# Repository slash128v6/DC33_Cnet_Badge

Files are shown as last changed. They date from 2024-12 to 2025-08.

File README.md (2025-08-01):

# DC33 CompuNet Badge - The Meshtastic Express

Introducing **The Meshtastic Express** — the open-source, networkless pager built for hackers, tinkerers, and technophiles. Powered by the Meshtastic protocol and fully customizable from the firmware up, this device lets you send messages over a decentralized mesh network — no cell towers, no Wi-Fi, no problem. Flash your own firmware, tweak the hardware with this highly customizable device and relive the 1990’s glory of belt-clip attached electronics.

Meshtastic devices use **LoRa (Long Range)** radio technology to send small data packets over several kilometers. Each device acts as a node in the mesh, forwarding messages to others until they reach their destination. Learn more at: 

[https://github.com/slash128v6/DC33_Cnet_Badge](https://github.com/slash128v6/DC33_Cnet_Badge)

[https://meshtastic.org](https://github.com/slash128v6/DC33_Cnet_Badge)

> [!TIP]
> **WARNING – DO NOT POWER THE HELTEC V3 LoRa UNIT WITHOUT THE ANTENNA ATTACHED! DAMAGE MAY RESULT**

# Section 1: Hardware Assembly

1.	Verify inventory:

| Qty	| Description |
|---|---|
|1	|PCB |
|1	|Heltec V3 LoRa Module Kit (includes antenna and 2x 18 pin headers)|
|1	|LiPo Battery|
|1	|GPS Module|
|1	|GPS Antenna|
|1	|Piezo Buzzer|
|1	|Vibration Motor|
|1	|6 Pin SAO Header|
|1	|12 Pin Header|
|2	|VHB Pads|
|1	|Case Bottom|
|1	|Case Top|
|1	|Case Clip|

2.	Solder the vibration motor. You can trim the wires but be very careful when stripping the ends, as the wire is very small gauge and easy to cut when stripping. Peel off the white tab and stick to the PCB. 

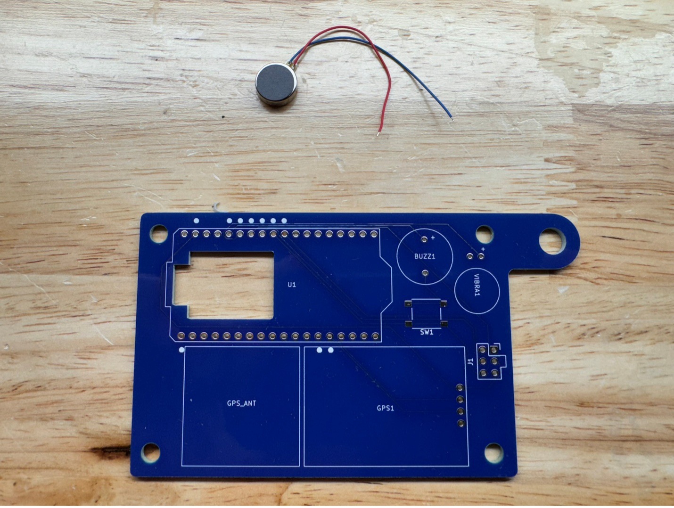
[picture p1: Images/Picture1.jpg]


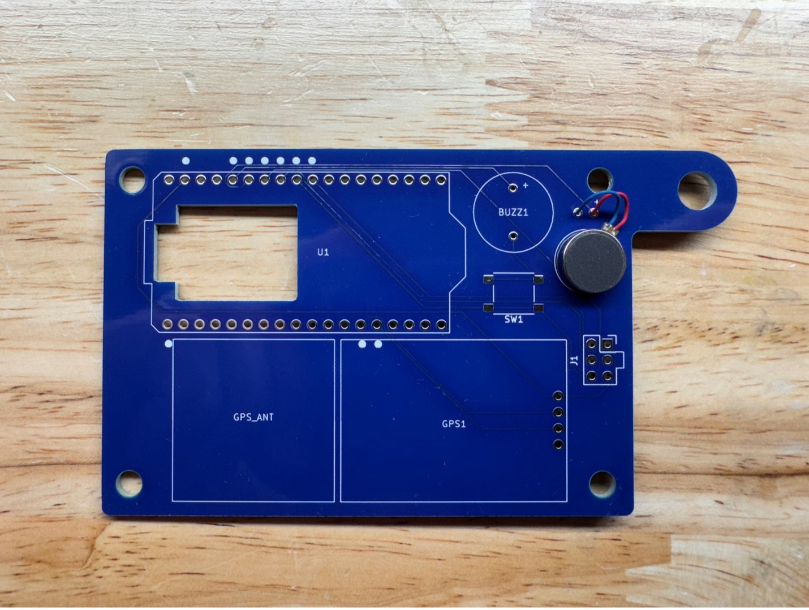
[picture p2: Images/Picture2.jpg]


3.	Solder the 6 pin SAO header with the tab aligned with the white silkscreen outline. Try to keep it as square as possible so SAOs are not crooked when installed. 

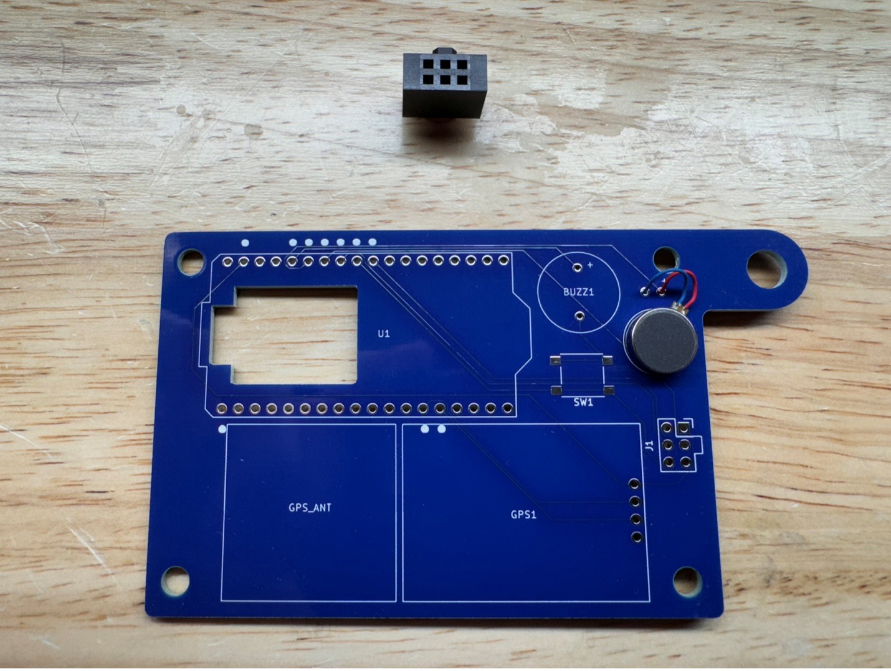
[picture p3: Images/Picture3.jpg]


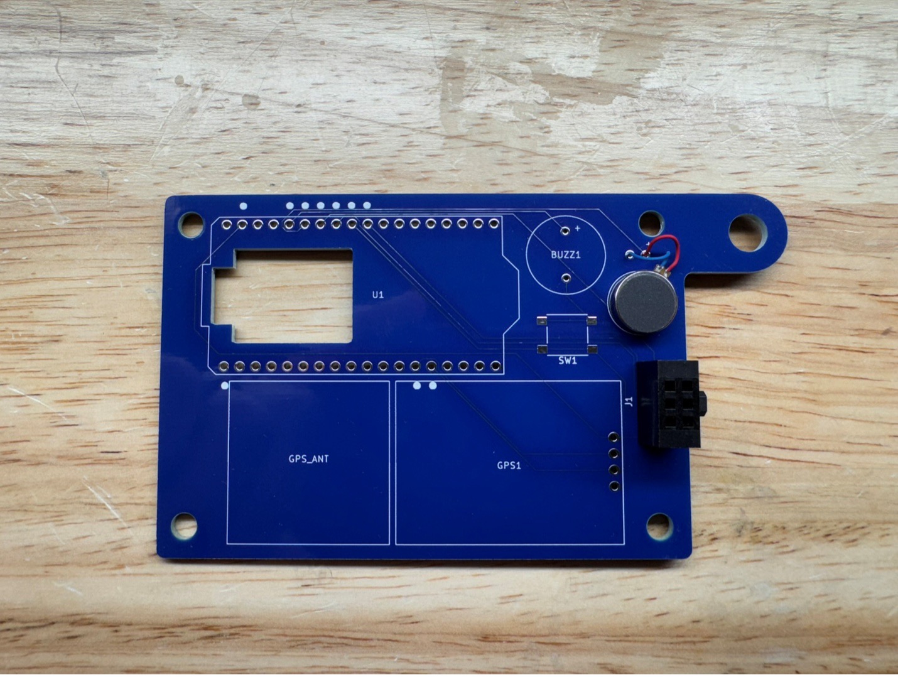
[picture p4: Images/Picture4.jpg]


4.	Solder the piezo buzzer noting the polarity. Remove the protective white sticker.

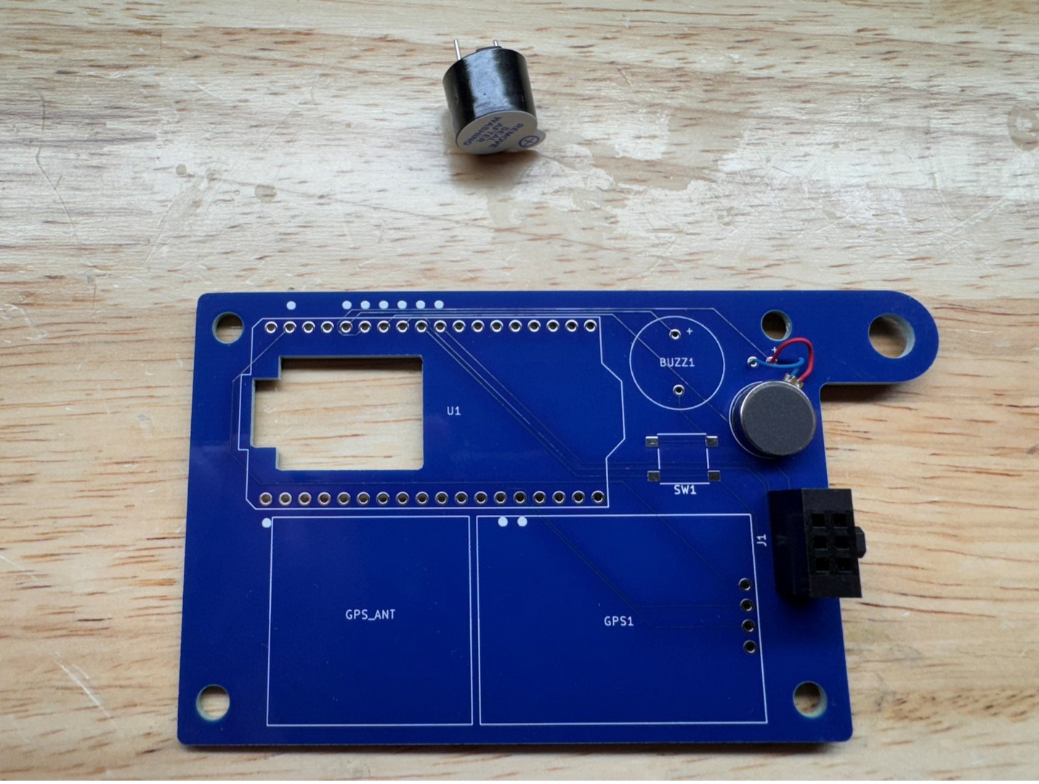
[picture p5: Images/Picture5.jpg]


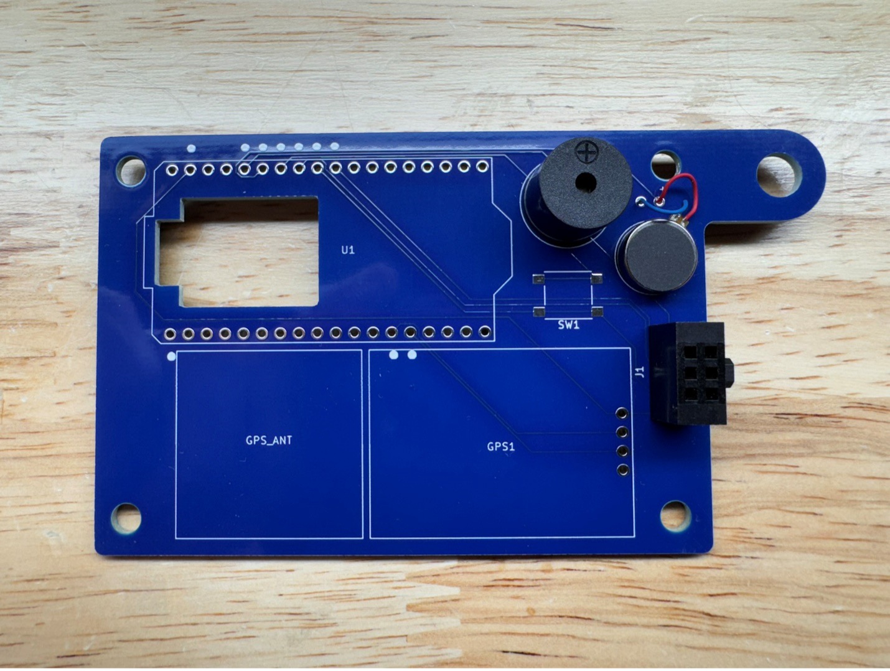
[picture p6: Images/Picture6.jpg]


5.	Solder the Heltec V3 LoRo module to the PCB using the 2x 18 pin headers included in the kit. The short side of the pins should face up through the module and the long side should face down through the PCB. To save time soldering, only the pins marked with white dots need to be soldered. Be careful soldering the 2 pins under the display ribbon cable. The cable is heat resistant, but can melt with too much heat.

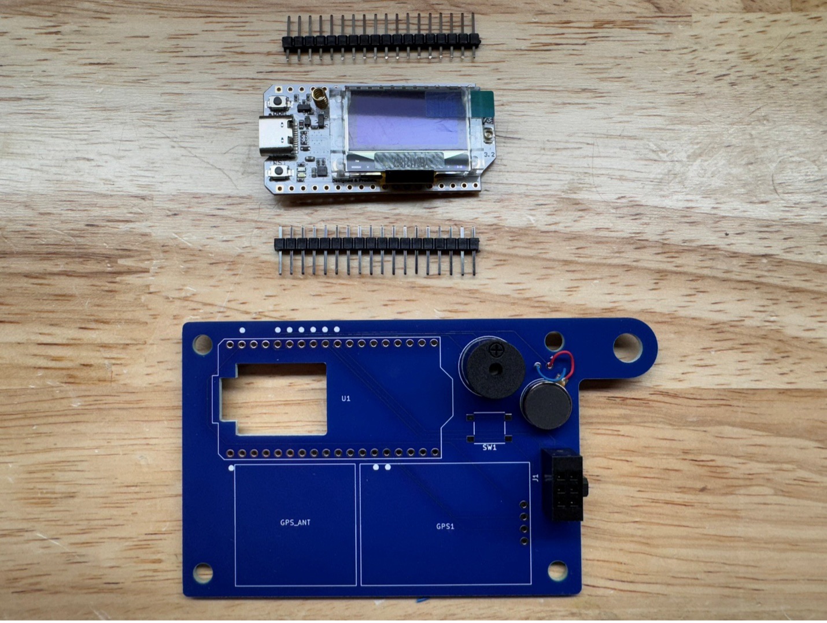
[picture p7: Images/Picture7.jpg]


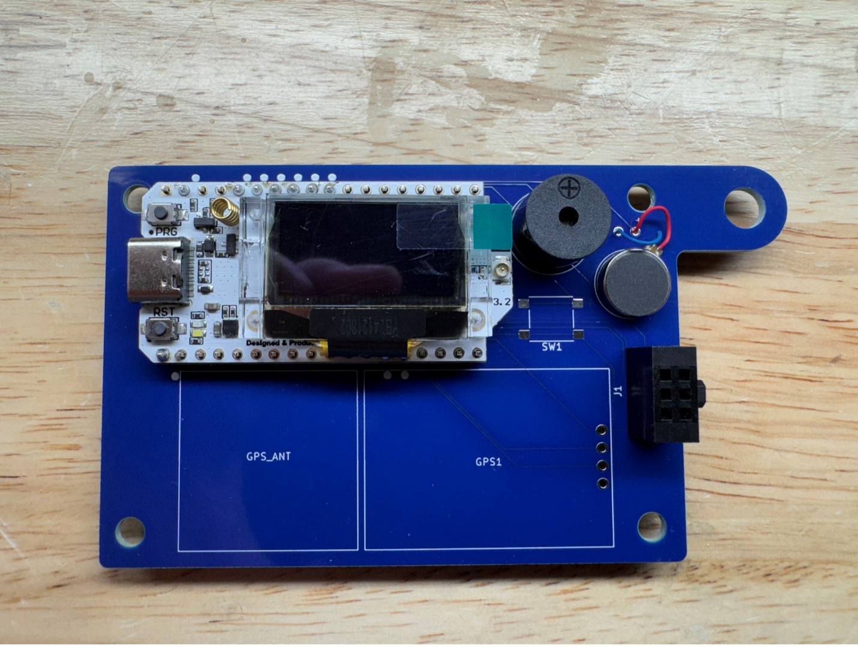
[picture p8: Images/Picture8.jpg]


6.	Cut off 4 pins from the 12 pin header and solder the GPS module to the PCB. The short side of the pins should face up through the module and the long side should face down through the PCB.

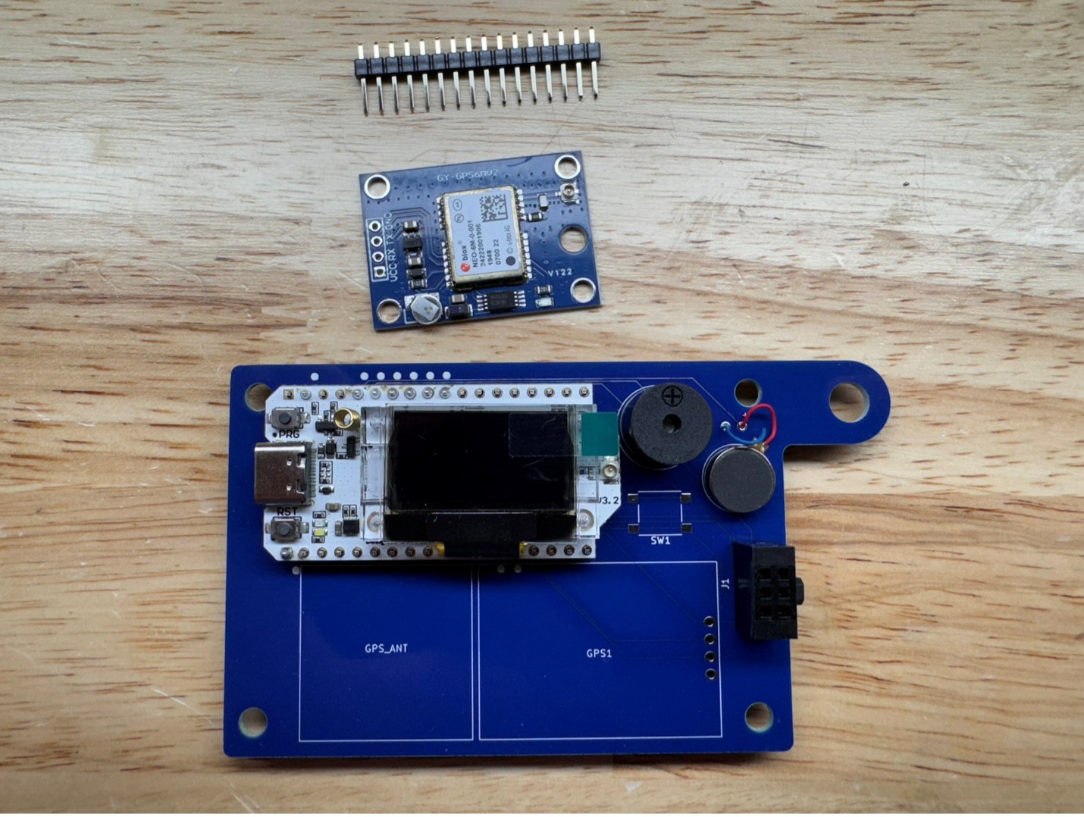
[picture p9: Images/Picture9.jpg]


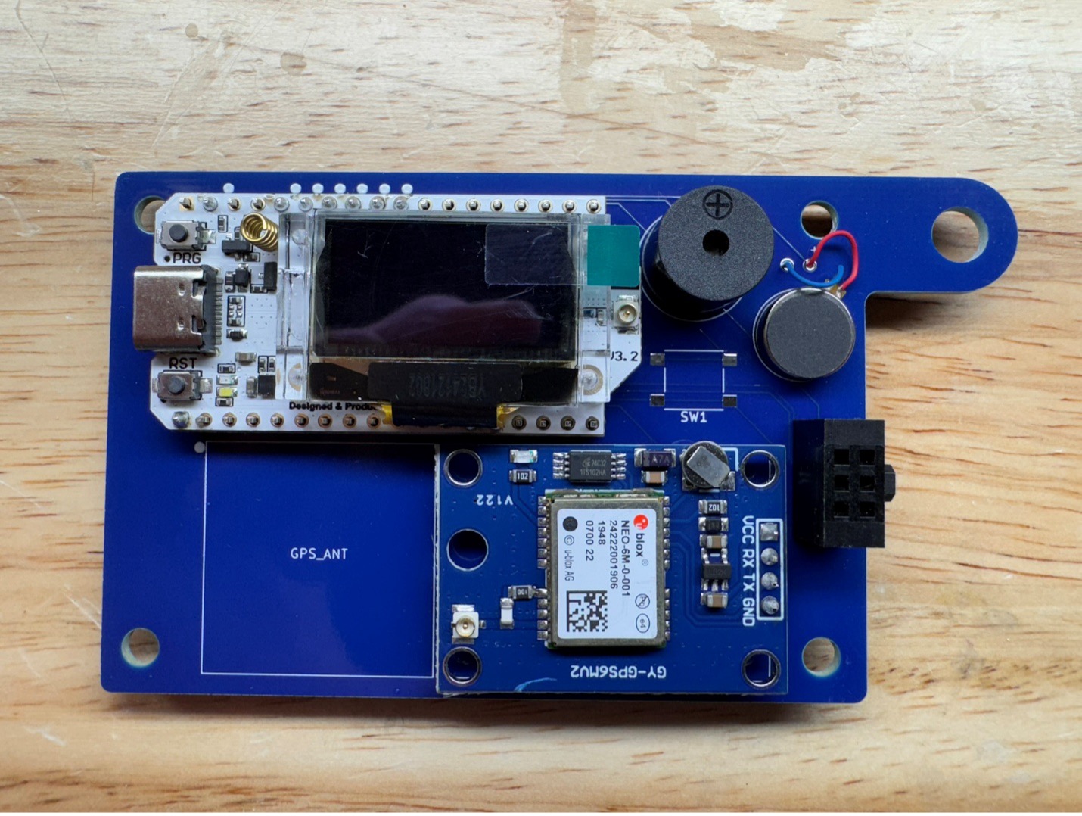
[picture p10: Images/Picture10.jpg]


7.	Attach the GPS antenna to the GPS module, pressing the connectors together until there is a slight click and they are parallel when viewed from the side. A fingernail or small flat bladed tool is helpful. Using one of the VHB pads affix the GPS antenna to the PCB, routing the wire underneath the lip. Make sure the GPS antenna is within the white square outline so the case will fit on later.

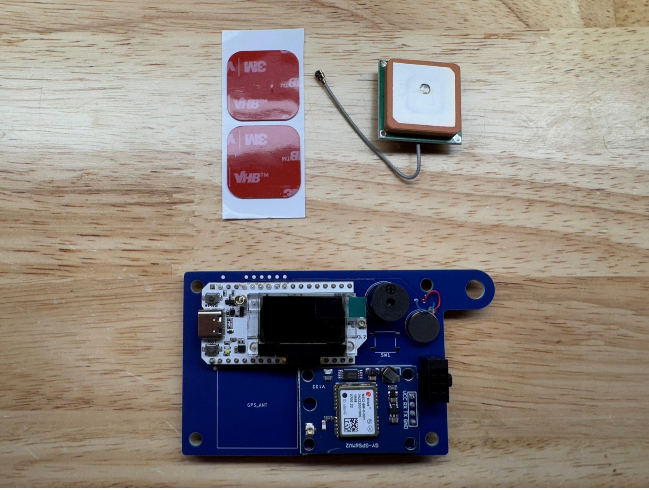
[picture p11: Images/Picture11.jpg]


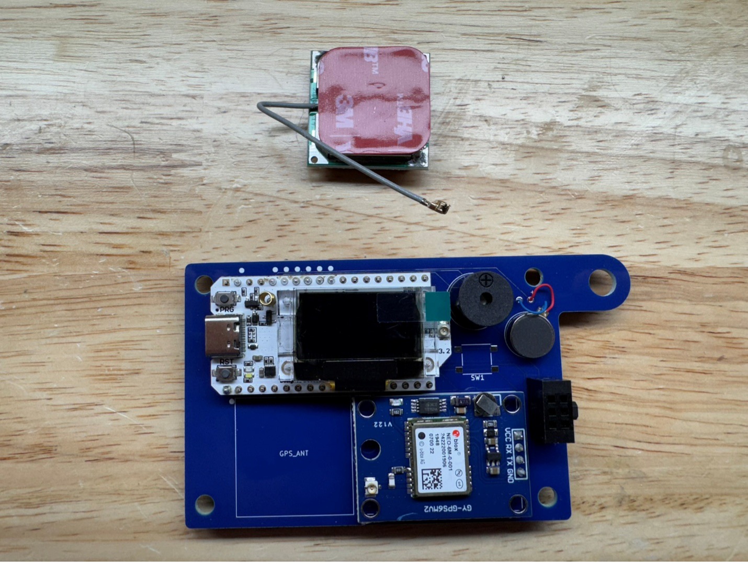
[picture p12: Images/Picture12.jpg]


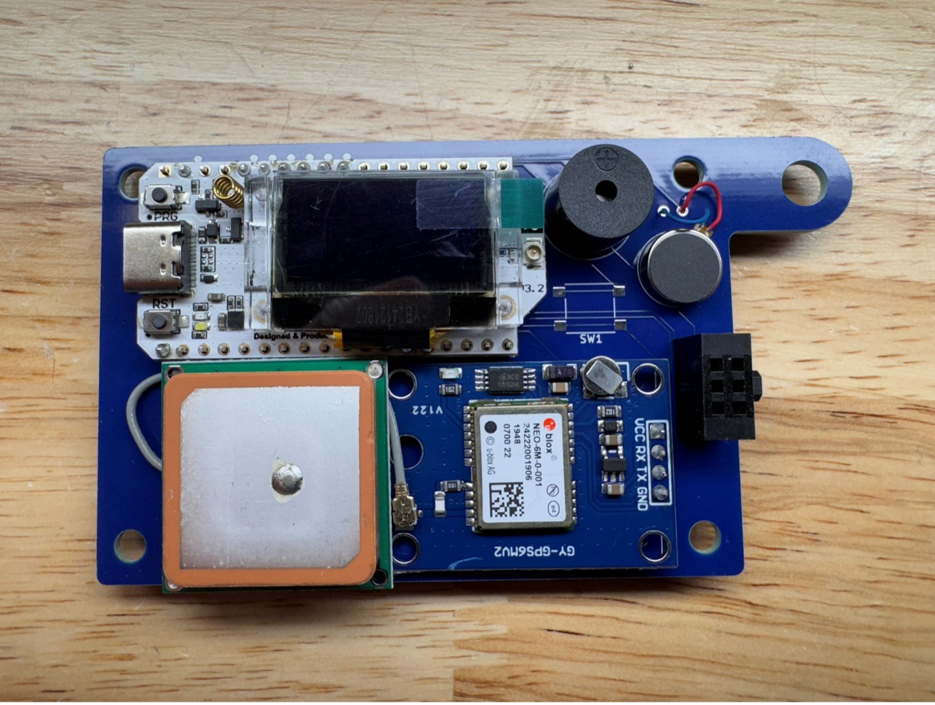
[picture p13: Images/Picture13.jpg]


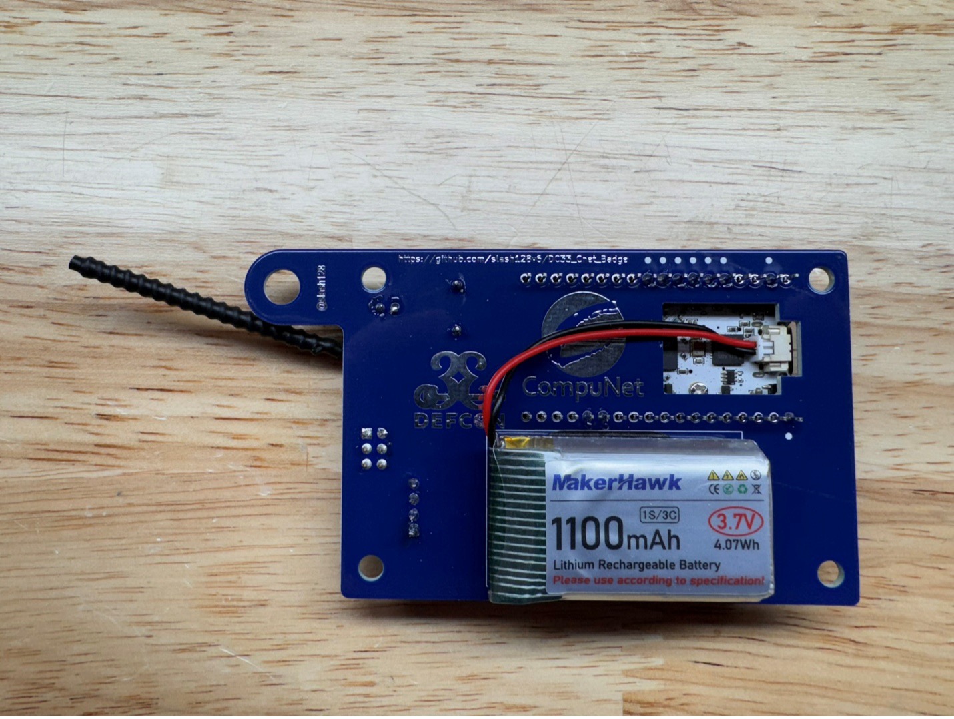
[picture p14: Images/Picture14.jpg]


8.	Mount the PCB in the lower case. Route the LoRa antenna horizontally along the top edge of the PCB as shown. A piece of tape helps. Align the top half of the case onto the lower half posts and press together until the gap between the two halves is gone. 

Slide the clip into the opening on the back until it clicks into place. 

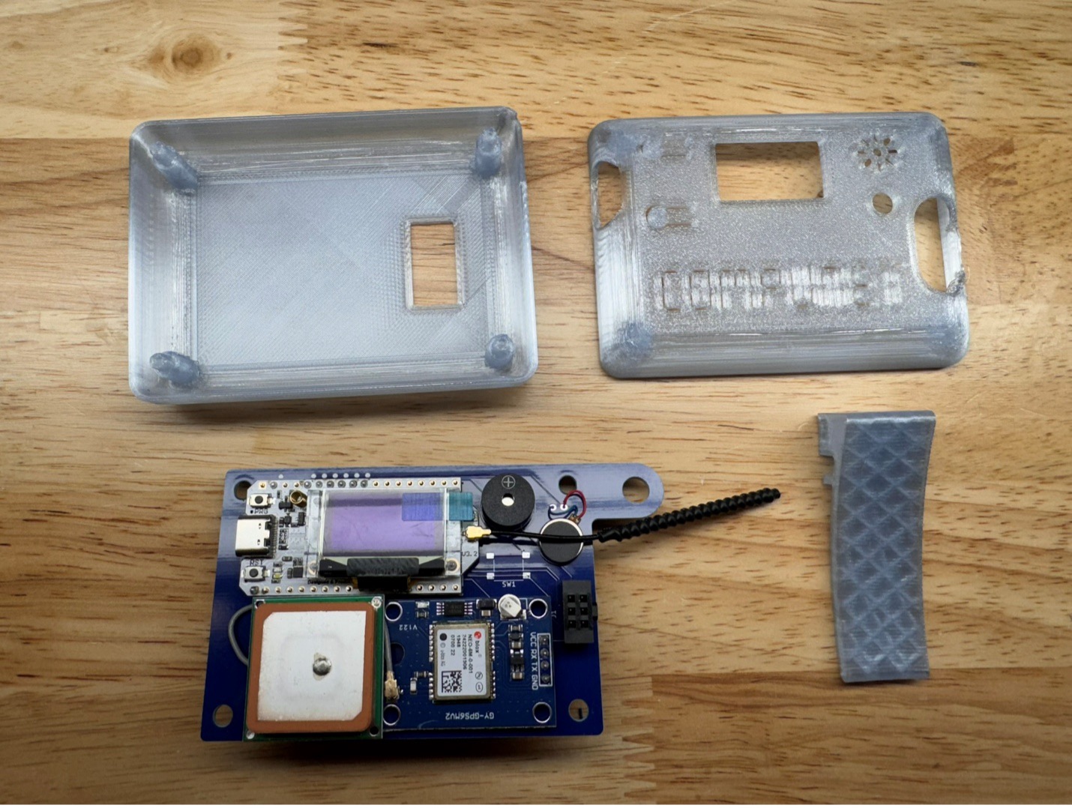
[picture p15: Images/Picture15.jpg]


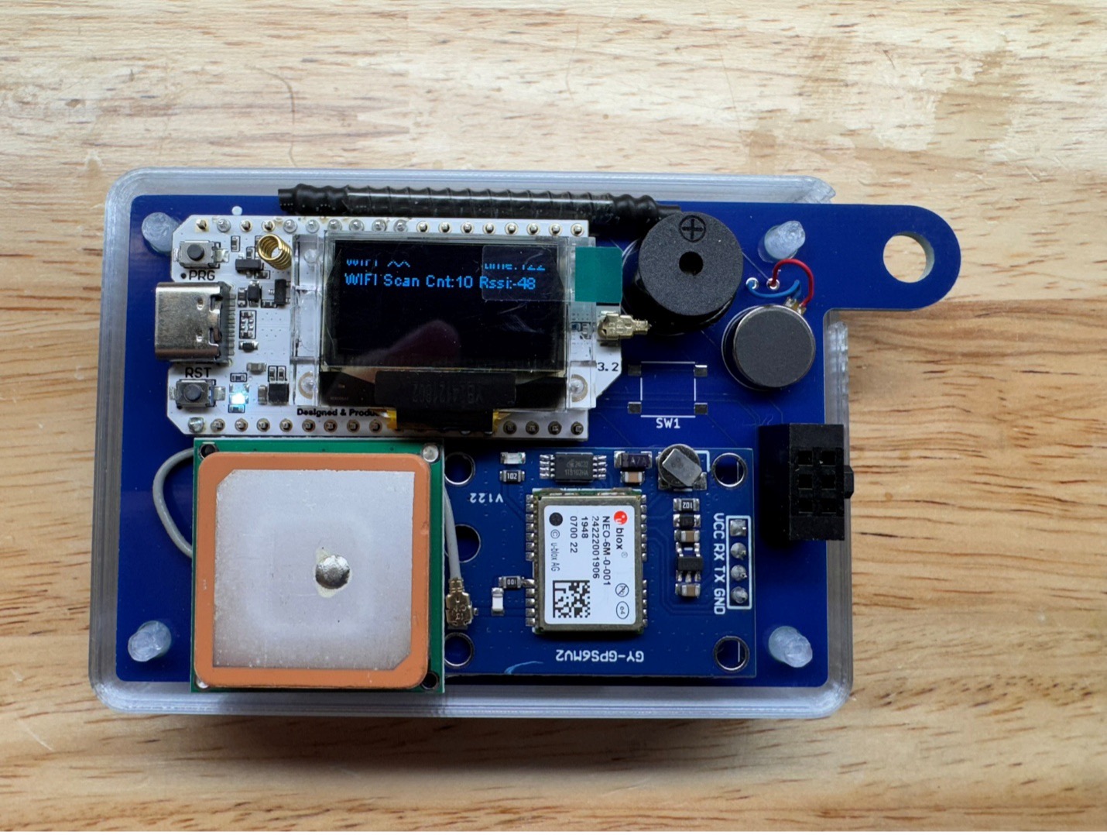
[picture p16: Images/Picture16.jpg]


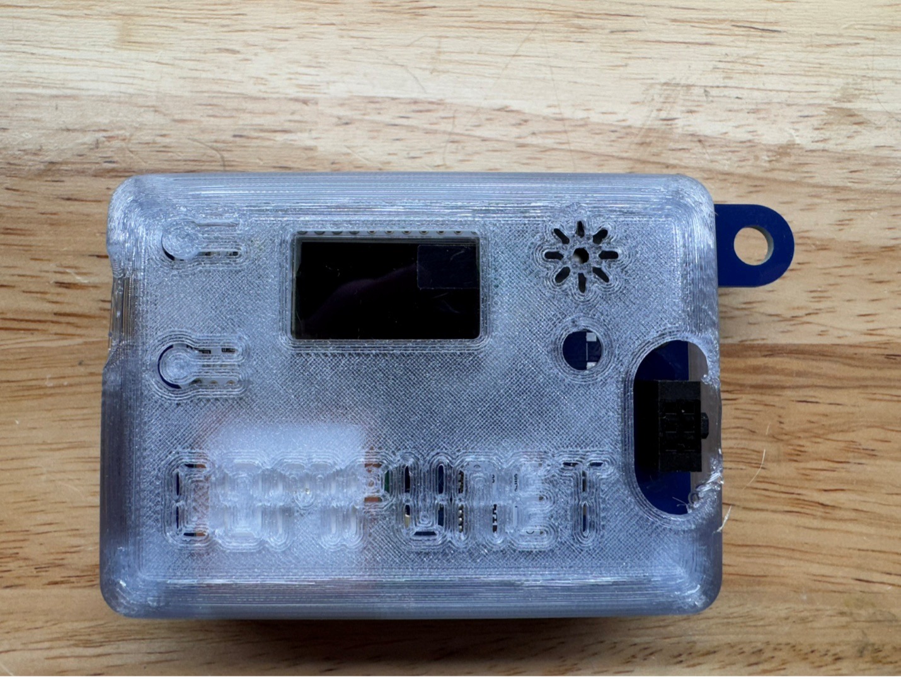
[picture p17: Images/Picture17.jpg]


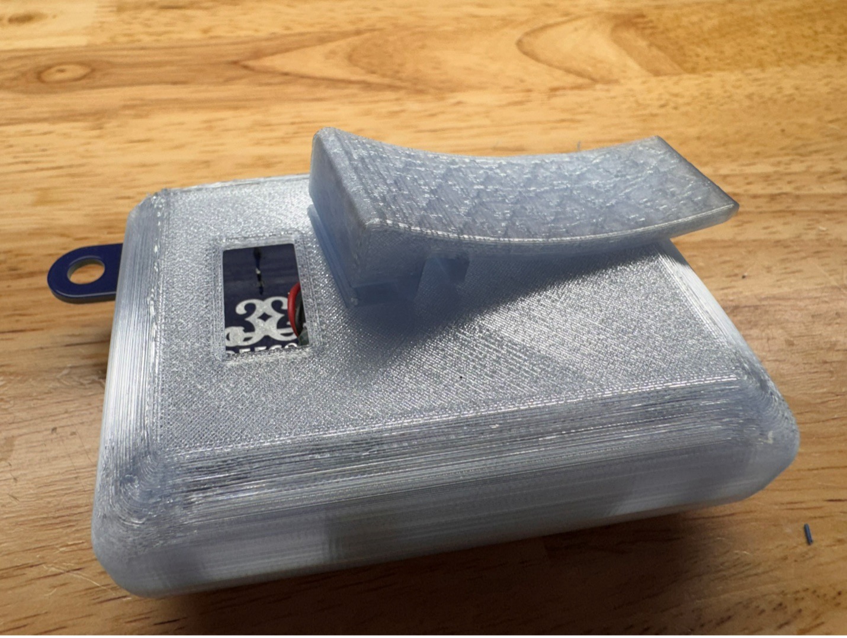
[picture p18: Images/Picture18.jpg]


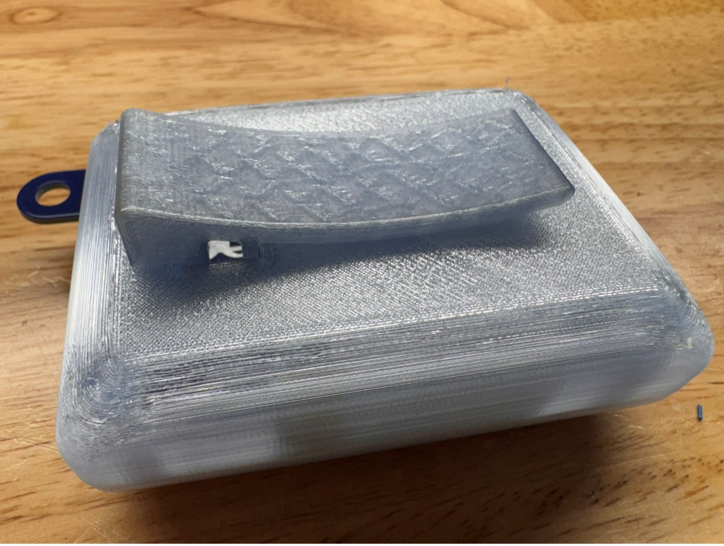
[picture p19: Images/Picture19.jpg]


# Section 2: Flashing & Configuration

1.	Install the CP210x Universal Windows Driver from https://www.silabs.com/developer-tools/usb-to-uart-bridge-vcp-drivers?tab=downloads. 

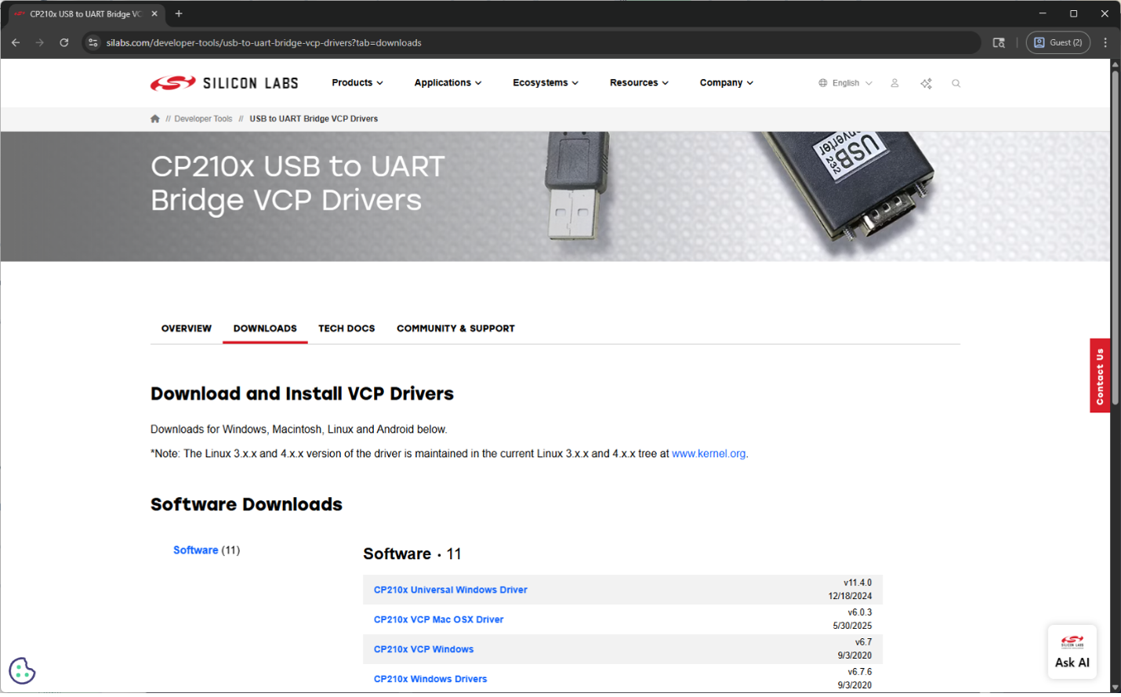
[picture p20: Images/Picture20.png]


2.	Connect the Heltec Lora V3 module to your PC with a USB-C cable. Open a browser to flasher.meshtastic.org. 

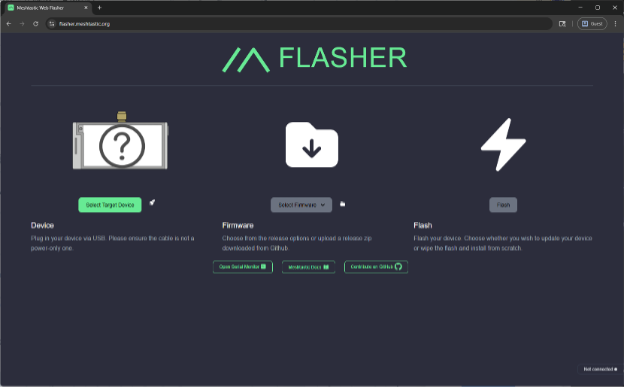
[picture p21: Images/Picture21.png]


3.	Click “Select Target Device” and select the “Heltec V3” device. 

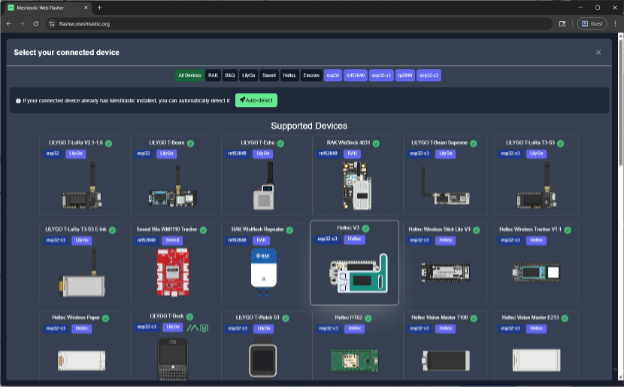
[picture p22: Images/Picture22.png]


4.	Select the latest stable firmware from the dropdown menu. 

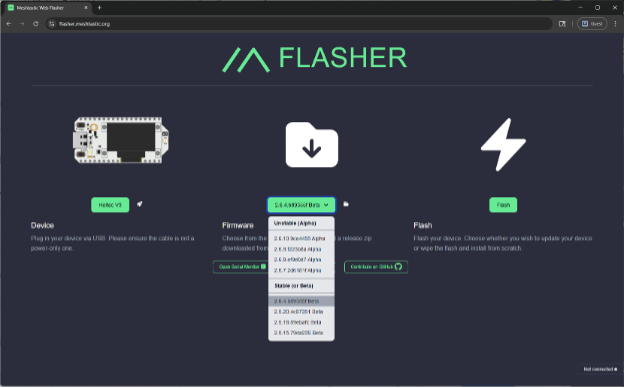
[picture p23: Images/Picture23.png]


5.	Click “Flash”. 

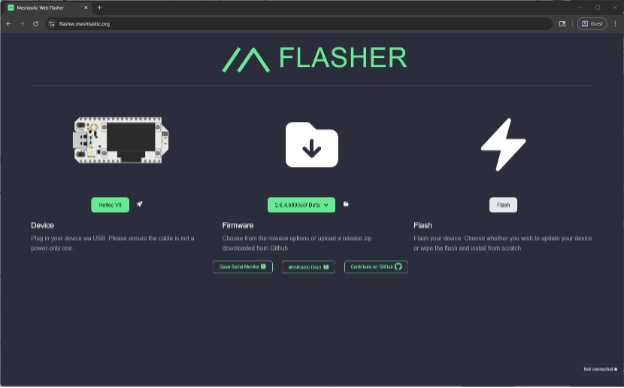
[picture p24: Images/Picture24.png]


6.	Click “Continue”.

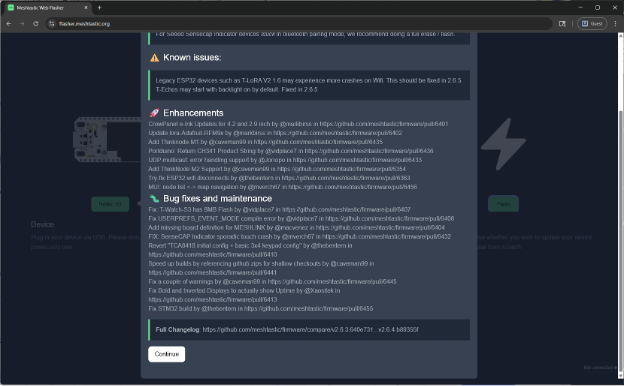
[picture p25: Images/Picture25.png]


7.	Toggle on the options “Full Erase and Install” and “Bundle Web UI” and click “Erase Flash and Install”. 

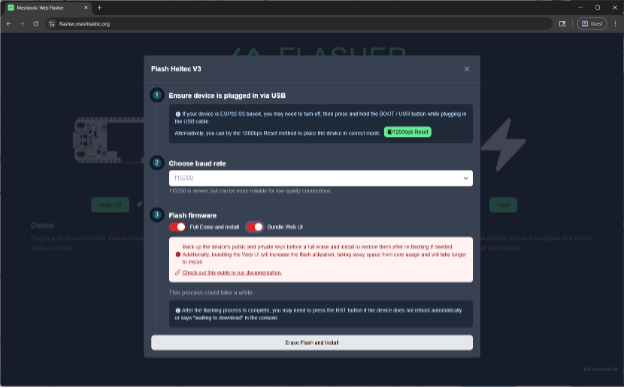
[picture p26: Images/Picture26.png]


8.	A selection dialog will appear. Select the CP2102 device and click “Connect”. 

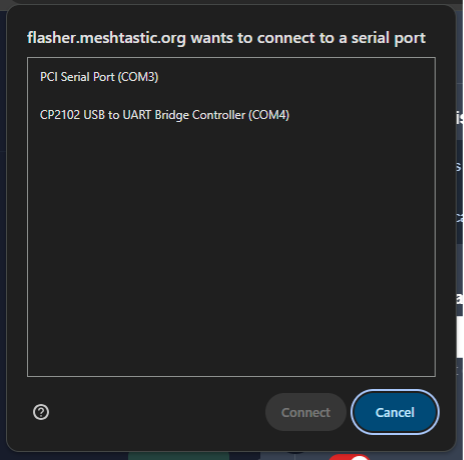
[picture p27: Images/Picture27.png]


9.	Flashing will begin. Wait for it to complete. 

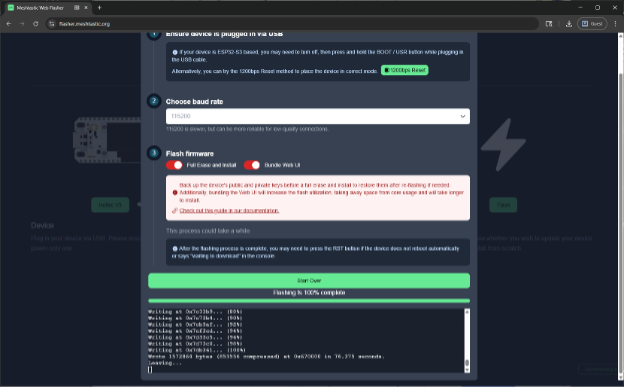
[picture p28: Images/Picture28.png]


10. Go to client.meshtastic.org and click “New Connection”. Don’t leave the flasher page open in another tab as it can interfere with the client connection. 

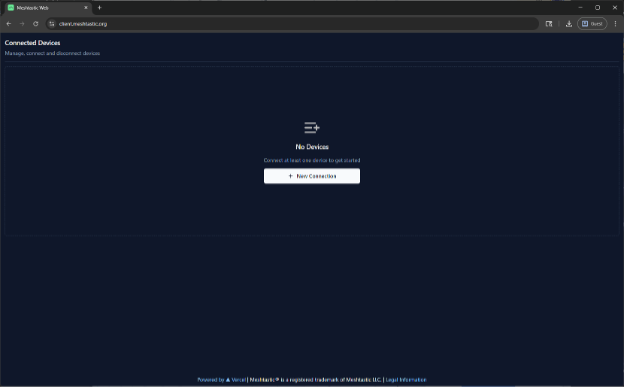
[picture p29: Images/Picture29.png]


11. Click on the “Serial” tab, then “New Device”. 

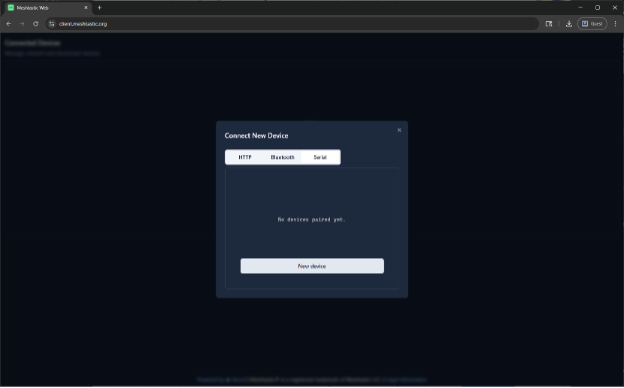
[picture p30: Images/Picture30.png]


12. A selection dialog will appear. Select the CP2102 device and click “Connect”. 

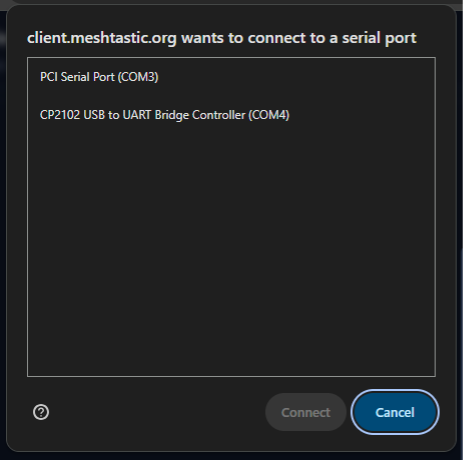
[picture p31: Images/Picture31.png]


13. Click the new device that appears. 

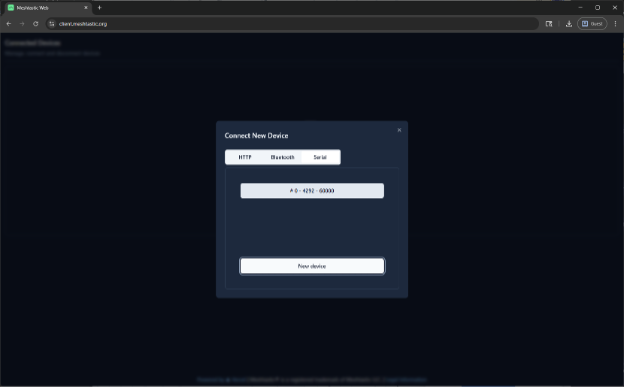
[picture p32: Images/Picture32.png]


14. Click on Config in the left menu, then the LoRa tab, set the location to “US”, then click the save floppy icon in the upper right corner. After the setting is saved the Heltec module will reboot. If it does not then try refreshing the page and try again.

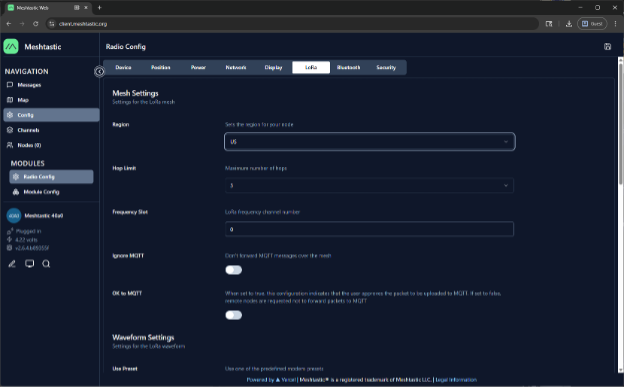
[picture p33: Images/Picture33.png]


15. Reconnect and click on the Display tab, set the Carousel Display to “15”, then click the save floppy icon in the upper right corner. After the setting is saved the Heltec module will reboot. If it does not then try refreshing the page and try again.

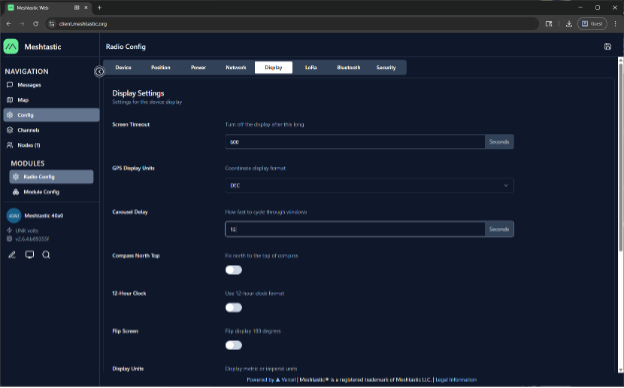
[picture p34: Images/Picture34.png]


16. Reconnect and click on the Position tab, set GPS Mode to Enables, the Receive Pin to “48” and the Transmit Pin to “47” then click the save floppy icon in the upper right corner. After the setting is saved the Heltec module will reboot. If it does not then try refreshing the page and try again.

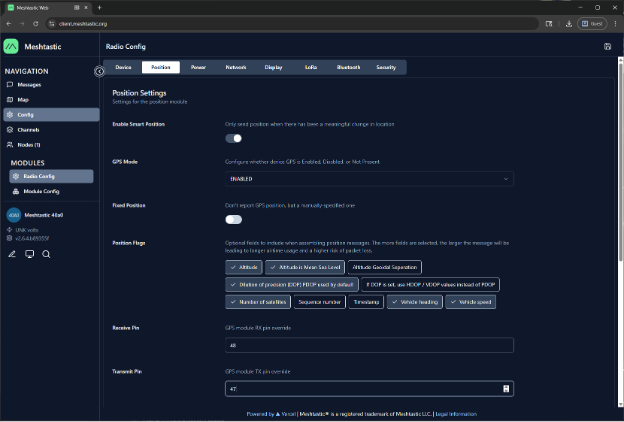
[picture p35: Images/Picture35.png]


17. Reconnect and click on Config and Module Config in the left menu, then the Ext Notif tab. Toggle on Enable External Notification then set Output Vibrate to “45” and Output Buzzer to “46” and enable all the toggle items EXCEPT “Use I2S Pin as Buzzer”, then click the save floppy icon in the upper right corner. After the setting is saved the Heltec module will reboot. If it does not then try refreshing the page and try again.

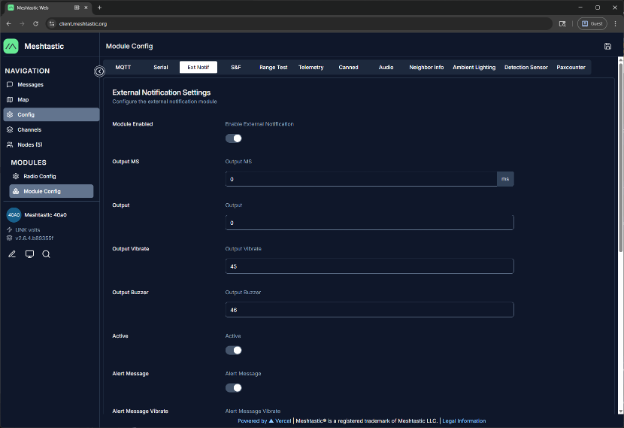
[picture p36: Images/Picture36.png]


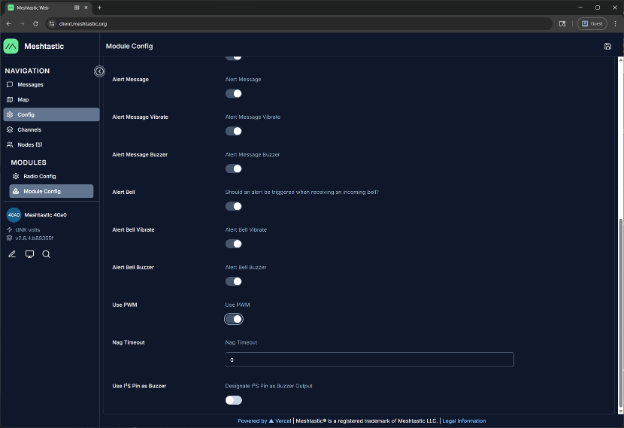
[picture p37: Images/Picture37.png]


# Section 3: Operation

1.	There are 2 buttons on the left side of the display. Some common button commands:

	*	Brief single presses of the top button will cycle through the screens on the display. By default the screen will turn off after 15 seconds. You can use the top button to wake the display. You can also set a longer screen timeout in settings.
	
	*	A long press of the top button will put the device in shutdown mode.

	*	A triple short press of the top button will disable GPS. Repeat to re-enable GPS.

	*	A single press of the top button will wake it back up. A single press of the bottom button will reboot the device. 

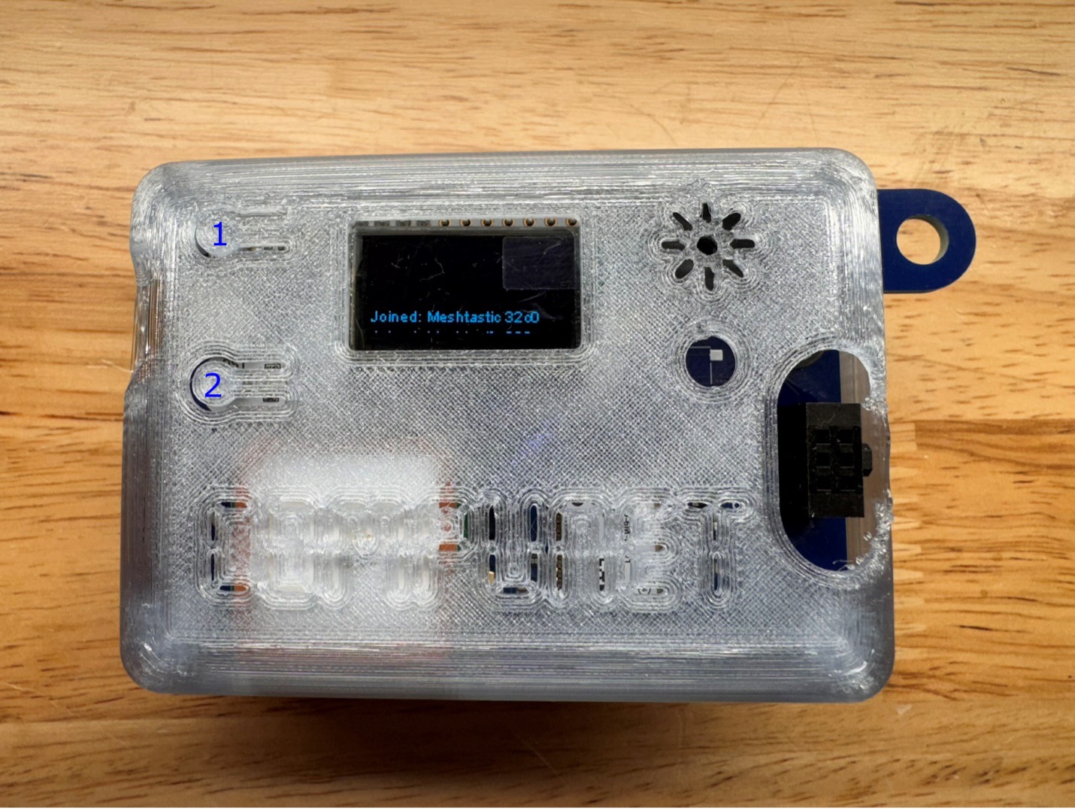
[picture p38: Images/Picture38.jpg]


2.	Download the Meshtastic app to your mobile device. It is supported on iOS and Android. Enable Bluetooth on your mobile device then open the Meshtastic app and go to the “Bluetooth” tab. You should see a list of available radios. Tap the radio with the ID that matches your device. You can view it on the info screen by cycling through with the top button.



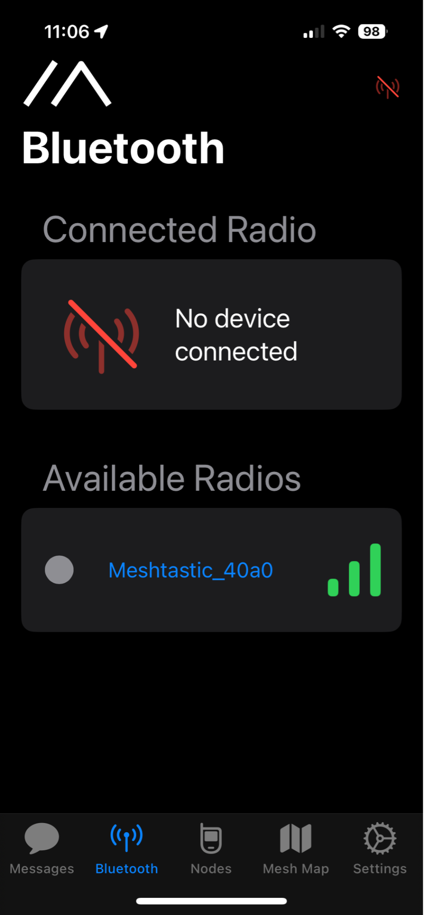
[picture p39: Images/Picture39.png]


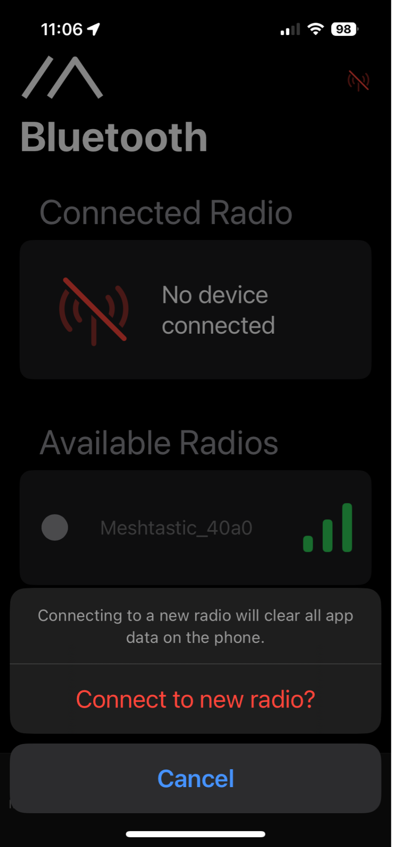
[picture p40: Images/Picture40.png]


3.	It will ask for a PIN that will be displayed on your radio’s display. Enter that PIN to connect







4.	The “Messages” tab is where you will send and receive messages. The “Primary Channel” reaches everyone on the mesh. 







5.	At this point you should have basic functionality. Feel free to explore the docs at [https://meshtastic.org/docs/introduction/](https://github.com/slash128v6/DC33_Cnet_Badge). Settings can be managed in the app as well, vs connecting to a PC and using the web interface at [https://client.meshtastic.org/](https://github.com/slash128v6/DC33_Cnet_Badge), though the web interface has more functionality. There is also a Python cli interface that allows bulk configuration changes and backup & restore. This is also covered on the Meshtastic website. A YAML config file with the basic settings applied in this doc is included in the “Software/configs” directory of the repo.

```
# start of Meshtastic configure yaml
config:
  device:
    buzzerGpio: 46
  display:
    autoScreenCarouselSecs: 15
    screenOnSecs: 31536000
  lora:
    region: US
  position:
    gpsMode: ENABLED
    rxGpio: 48
    txGpio: 47
module_config:
  externalNotification:
    active: true
    alertBell: true
    alertBellBuzzer: true
    alertBellVibra: true
    alertMessage: true
    alertMessageBuzzer: true
    alertMessageVibra: true
    enabled: true
    outputBuzzer: 46
    outputVibra: 45
    usePwm: true
```

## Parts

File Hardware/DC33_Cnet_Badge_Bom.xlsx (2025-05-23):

 | Qty Required | Qty per Unit | Qty Unit to Order | Link
DigiKey
Female Header | 100 | 1 | 100 | https://www.digikey.com/en/products/detail/sullins-connector-solutions/SFH11-NBPC-D03-ST-BK/4558818
Pin Header | 100 | 1 | 100 | https://www.digikey.com/en/products/detail/adam-tech/PH1-16-UA/9830344
Static Bag | 100 | 1 | 100 | https://www.digikey.com/en/products/detail/scs/30068/3430458
Optional -
Pushbutton | 100 | 1 | 100 | https://www.digikey.com/en/products/detail/c-k/PTS645SM13SMTR92-LFS/7056043
Amazon
Heltec V3 | 100 | 1 | 100 | https://www.amazon.com/dp/B076MSLFC9?ref=ppx_yo2ov_dt_b_fed_asin_title&th=1
LiPo Battery | 100 | 1 | 100 | https://www.amazon.com/dp/B0D7MC714N?ref=ppx_yo2ov_dt_b_fed_asin_title&th=1
GPS Module | 100 | 4 | 25 | https://www.amazon.com/dp/B0CQ4W9S7T?ref=ppx_yo2ov_dt_b_fed_asin_title
Buzzer | 100 | 1 | 100 | https://www.amazon.com/dp/B07VK1GJ9X?ref=ppx_yo2ov_dt_b_fed_asin_title
Vibration Motor | 100 | 40 | 3 | https://www.amazon.com/dp/B0D6BM2VTY/?coliid=I1SXIQM8XB9OPB&colid=12X8T1XUDE6S9
Double-sided VHB | 200 | 40 | 5 | https://www.amazon.com/dp/B0D95DVZSJ?ref=ppx_yo2ov_dt_b_fed_asin_title&th=1

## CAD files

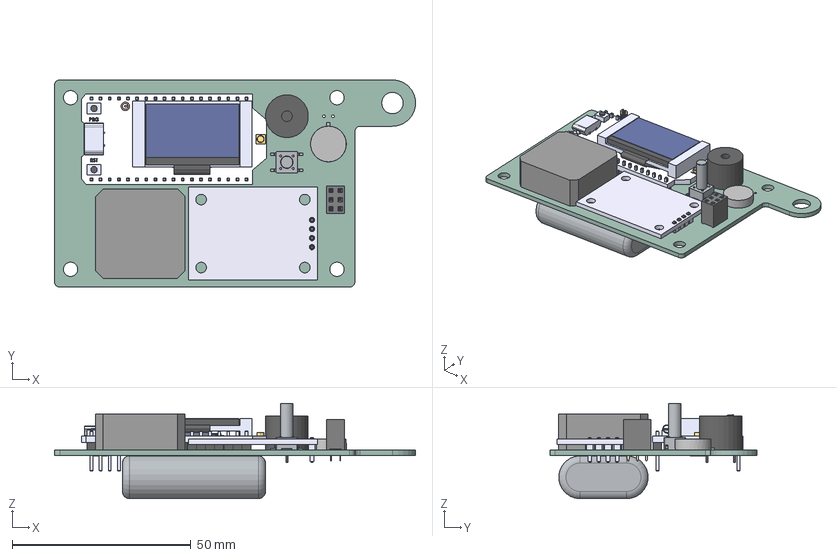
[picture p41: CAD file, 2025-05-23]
Hardware/3D Models/DC33_Cnet_Badge_Main.step
101.0 x 58.0 x 26.7 mm
Vibra1
PinSocket_2x03_P2.54mm_Vertical
Buzz1
HiLetGo_GPS_Antenna
heltec_wifi_32_asm2
HiLetGo_GPS_Module
Tactile_Switch-13mm
LiPo
DC33_Cnet_Badge_Main_PCB

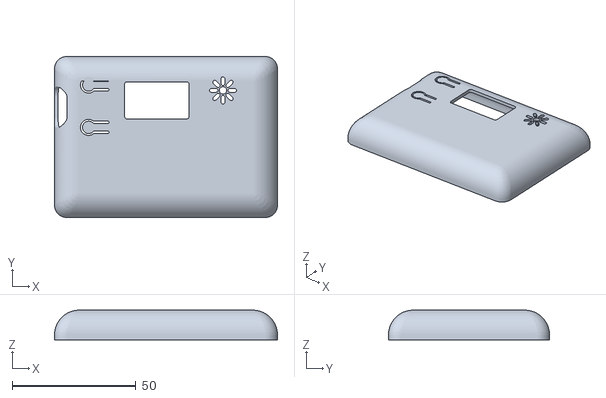
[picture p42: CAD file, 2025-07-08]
Hardware/3D Printed Parts/DC33_Cnet_Badge_Case/DC33_Cnet_Badge_Case_JP Edit-Top Case - Cleaned Up.stl
90.0 x 65.0 x 12.0

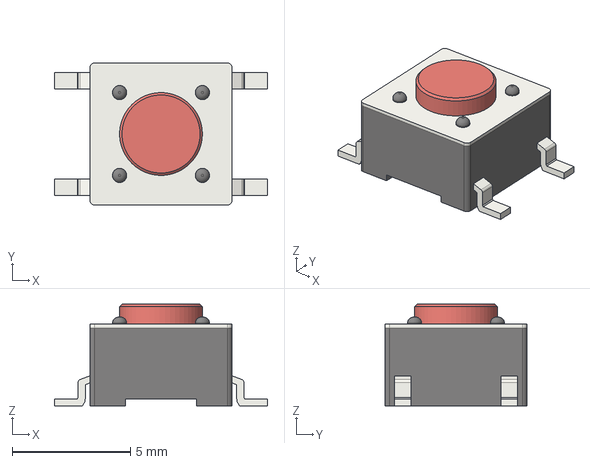
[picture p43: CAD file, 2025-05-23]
Hardware/Components/Tactile Switch/SW_SPST_PTS645.step
9.00 x 6.00 x 4.30 mm

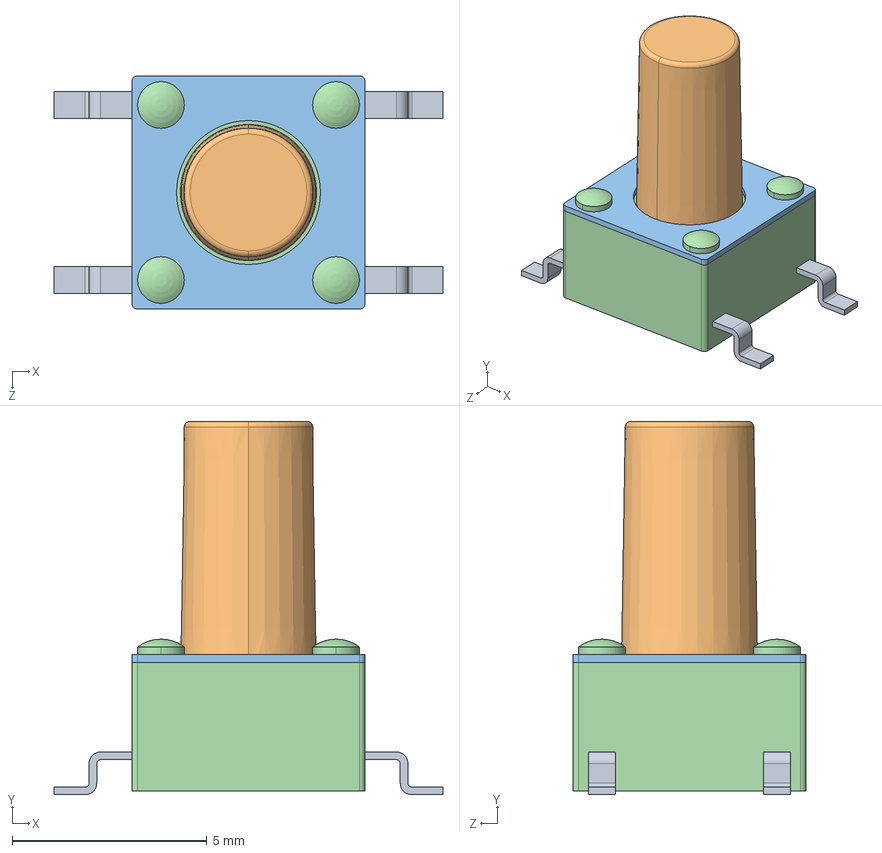
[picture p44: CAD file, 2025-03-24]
Hardware/Components/TS04-66-95-BK-100-SMT/TS04-66-95-BK-100-SMT.step
10.0 x 9.60 x 6.00 mm

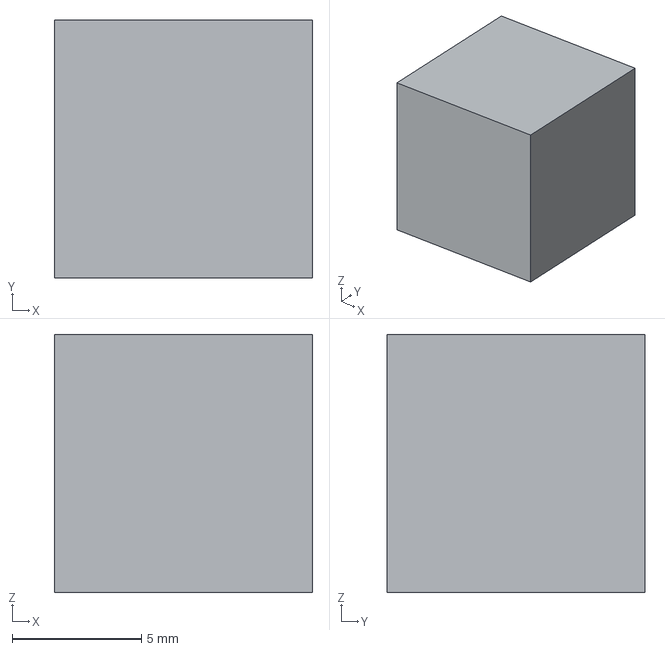
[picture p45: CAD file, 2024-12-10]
Hardware/3D Models/Unnamed-Body.step
10.0 x 10.0 x 10.0 mm

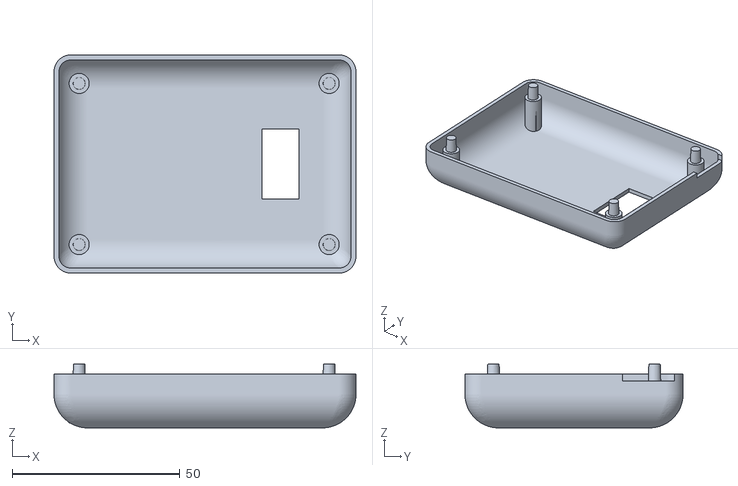
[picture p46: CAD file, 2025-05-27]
Hardware/3D Printed Parts/DC33_Cnet_Badge_Case/DC33_Cnet_Badge_Case-Bottom Case.stl
90.0 x 65.0 x 19.0

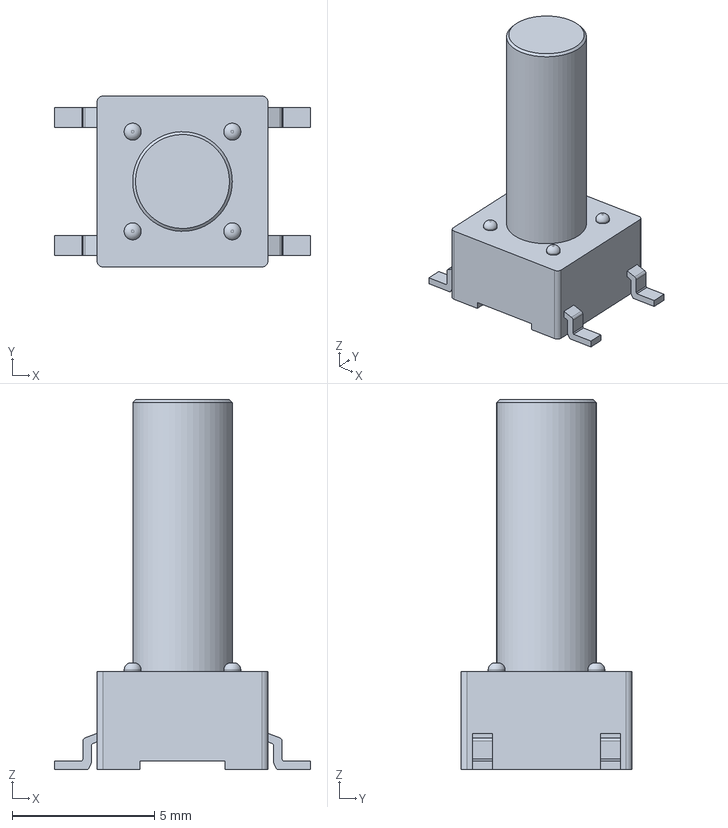
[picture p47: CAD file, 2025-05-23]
Hardware/Components/Tactile Switch/Tactile_Switch.FCStd
9.00 x 6.00 x 13.0 mm

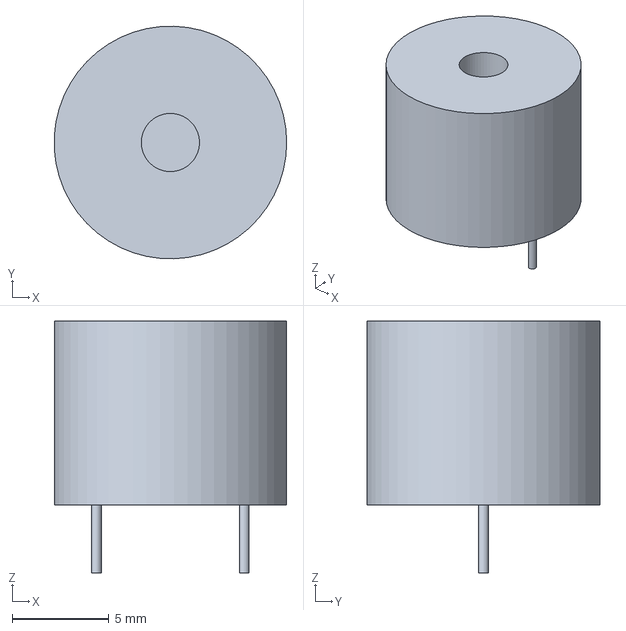
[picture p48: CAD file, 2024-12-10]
Hardware/3D Models/Buzz1.step
12.0 x 12.0 x 13.0 mm

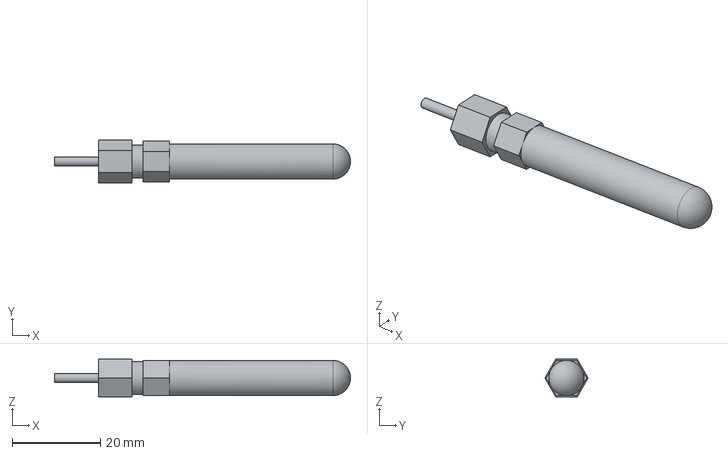
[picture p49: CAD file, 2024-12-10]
Hardware/3D Models/LoRa_Antenna.step
67.0 x 9.81 x 8.50 mm

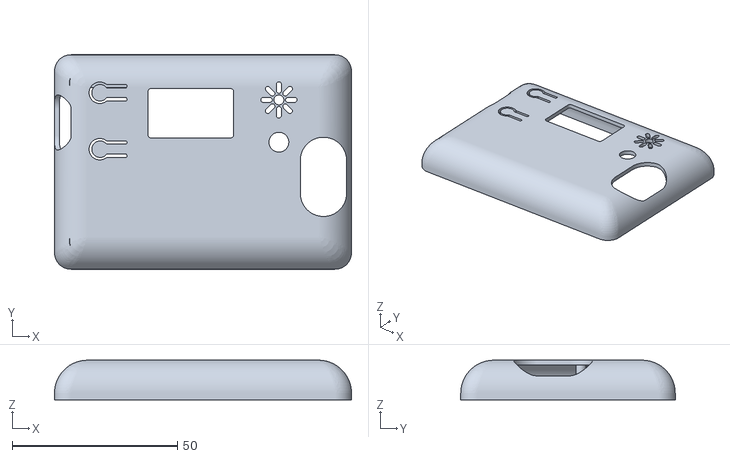
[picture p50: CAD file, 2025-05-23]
Hardware/3D Printed Parts/DC33_Cnet_Badge_Case/DC33_Cnet_Badge_Case-Top Case - No Logo.stl
90.0 x 65.0 x 12.0

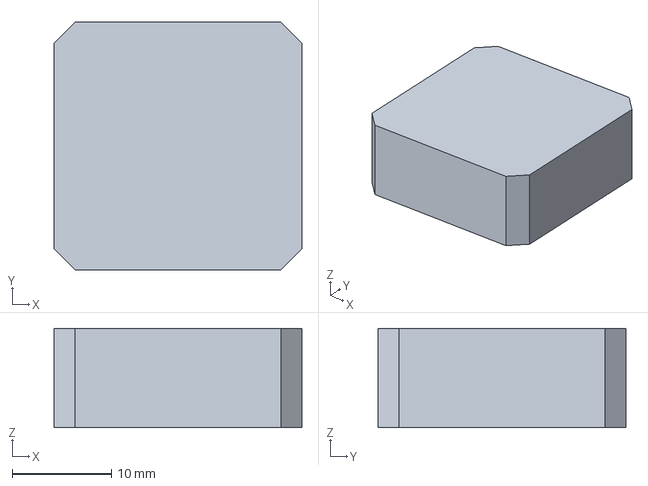
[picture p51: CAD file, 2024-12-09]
Hardware/3D Models/HiLetGo_GPS_Antenna.step
25.0 x 25.0 x 10.0 mm

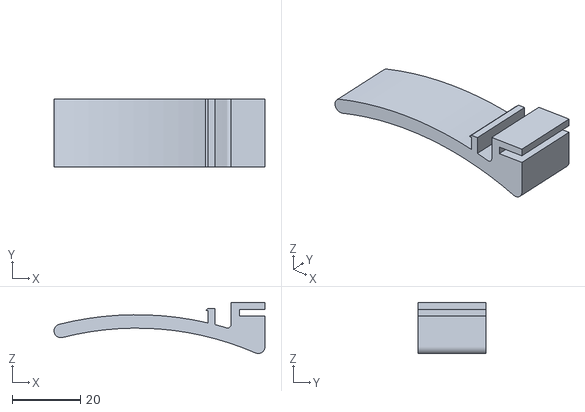
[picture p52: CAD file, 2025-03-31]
Hardware/3D Printed Parts/DC33_Cnet_Badge_Case/DC33_Cnet_Badge_Case-Clip.stl
62.0 x 20.0 x 15.0

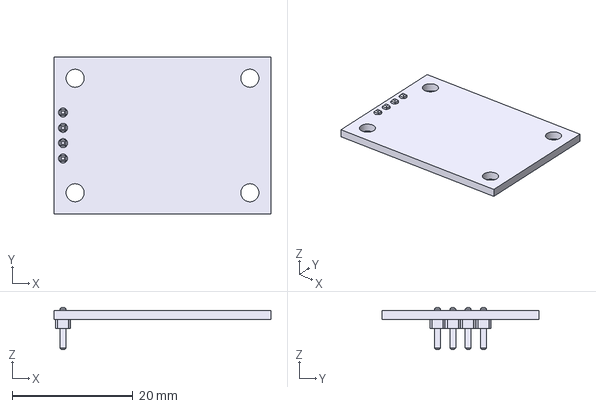
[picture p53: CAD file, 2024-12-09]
Hardware/3D Models/HiLetGo_GPS_Module.step
36.0 x 26.0 x 7.00 mm

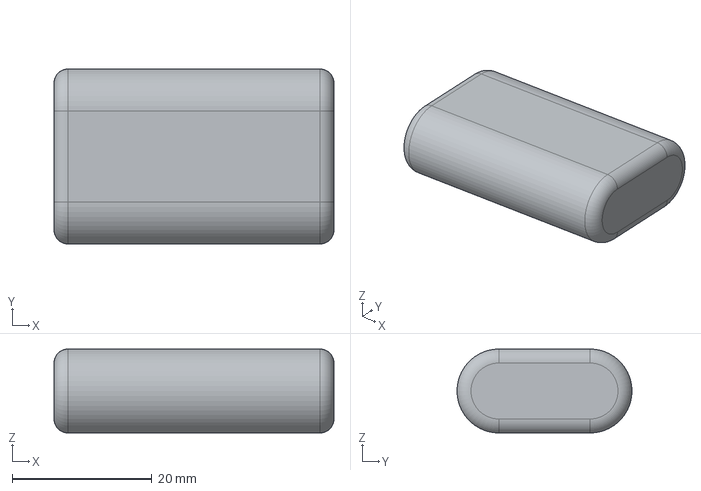
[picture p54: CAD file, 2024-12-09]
Hardware/3D Models/LiPo.step
40.0 x 25.0 x 12.0 mm

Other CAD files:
Hardware/3D Printed Parts/DC33_Cnet_Badge_Case/DC33_Cnet_Badge_Case-Top Case - CNet Logo.stl
Hardware/Components/Tactile Switch/Tactile_Switch-13mm.step
Hardware/3D Models/Vibra1.step
Hardware/3D Models/Buzz1.FCStd
Hardware/3D Models/DC33_Cnet_Badge_Main.FCStd
Hardware/3D Models/HiLetGo_GPS_Antenna.FCStd
Hardware/3D Models/HiLetGo_GPS_Module.FCStd
Hardware/3D Models/LiPo.FCStd
Hardware/3D Models/LoRa_Antenna.FCStd
Hardware/3D Models/Vibra1.FCStd

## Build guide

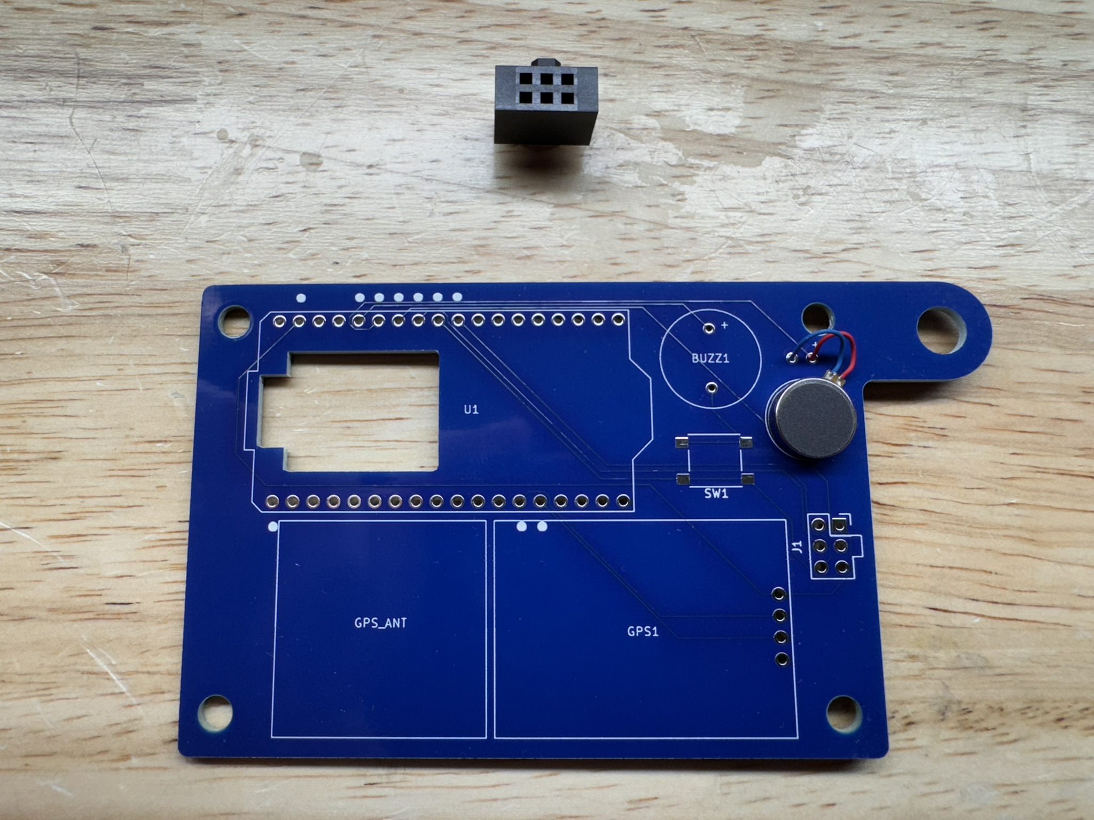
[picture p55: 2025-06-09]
Docs/WIP/Images/Hardware Assembly/IMG_2637.JPEG

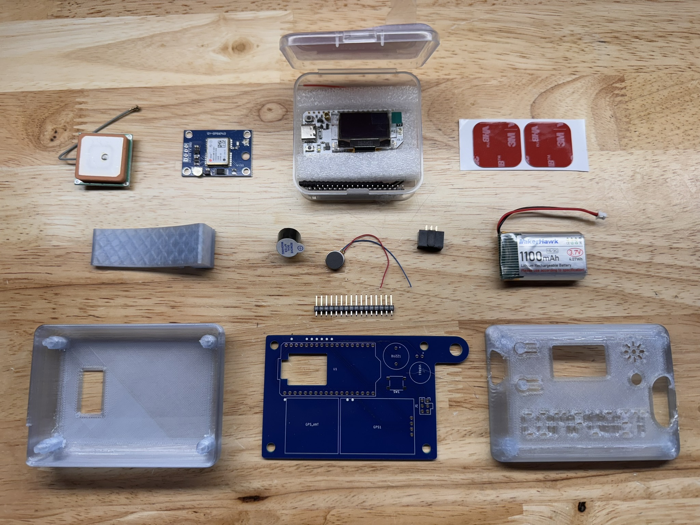
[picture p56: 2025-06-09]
Docs/WIP/Images/Hardware Assembly/IMG_2634.JPEG

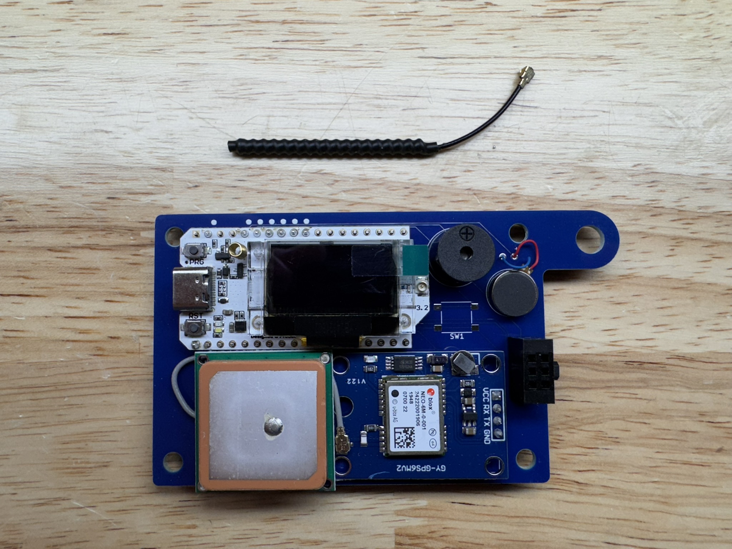
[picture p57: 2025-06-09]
Docs/WIP/Images/Hardware Assembly/IMG_2648.JPEG

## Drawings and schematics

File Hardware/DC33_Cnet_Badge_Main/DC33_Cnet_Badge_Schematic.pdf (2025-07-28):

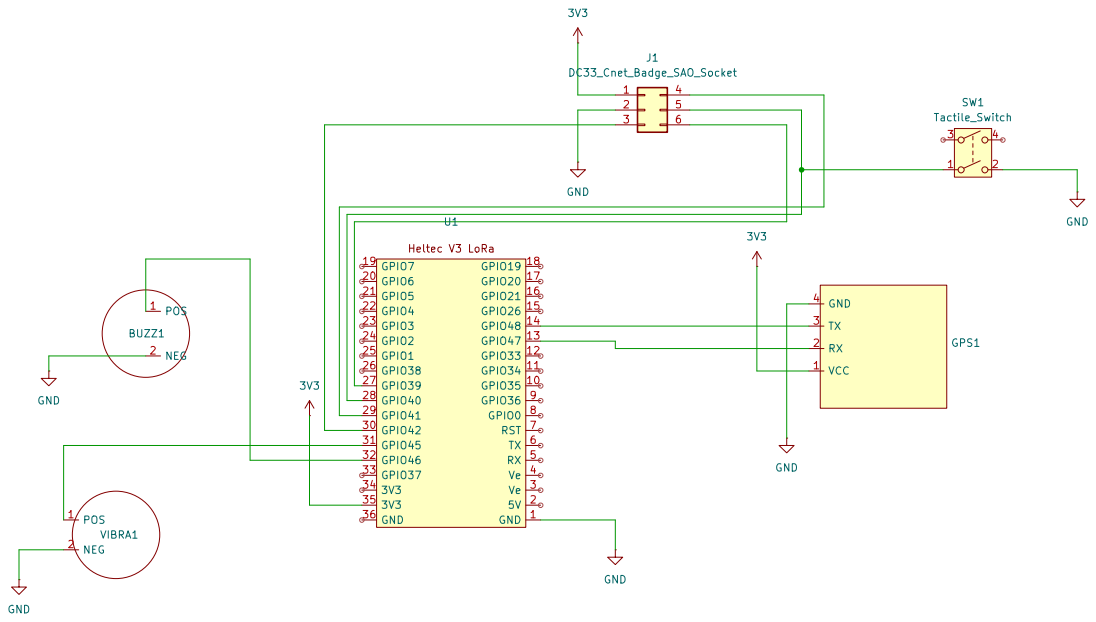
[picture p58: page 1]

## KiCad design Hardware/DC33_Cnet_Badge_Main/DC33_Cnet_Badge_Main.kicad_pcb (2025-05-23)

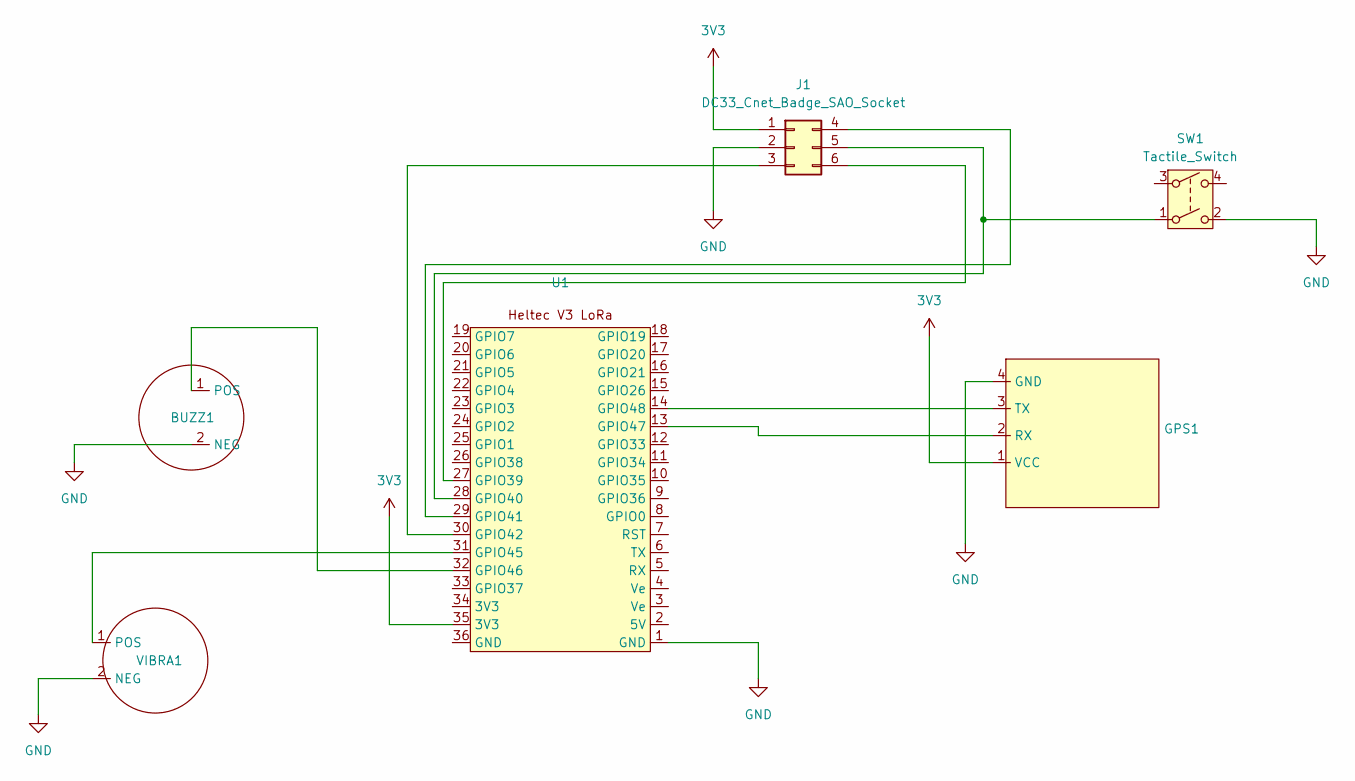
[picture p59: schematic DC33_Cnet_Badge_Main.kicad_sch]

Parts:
BUZZ1: DC33_Cnet_Badge_Buzzer
GPS1: DC33_Cnet_Badge_HiLetgo_GPS
J1: DC33_Cnet_Badge_SAO_Socket
SW1: Tactile_Switch; Tactile_Switch-13mm
U1: DC33_Cnet_Badge_Heltec_V3_LoRa
VIBRA1: DC33_Cnet_Badge_Vibra

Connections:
3V3: GPS1.1 (VCC), J1.1 (+3.3V), U1.35 (3V3)
GND: BUZZ1.2 (NEG), GPS1.4 (GND), J1.2 (GND), SW1.2, U1.1 (GND), VIBRA1.2 (NEG)
unnamed: BUZZ1.1 (POS), U1.32 (GPIO46)
unnamed: GPS1.2 (RX), U1.13 (GPIO47)
unnamed: GPS1.3 (TX), U1.14 (GPIO48)
unnamed: J1.5 (GPIO1), SW1.1, U1.28 (GPIO40)
unnamed: J1.6 (GPIO2), U1.27 (GPIO39)
unnamed: J1.4 (SCL), U1.29 (GPIO41)
unnamed: J1.3 (SDA), U1.30 (GPIO42)
unnamed: U1.31 (GPIO45), VIBRA1.1 (POS)

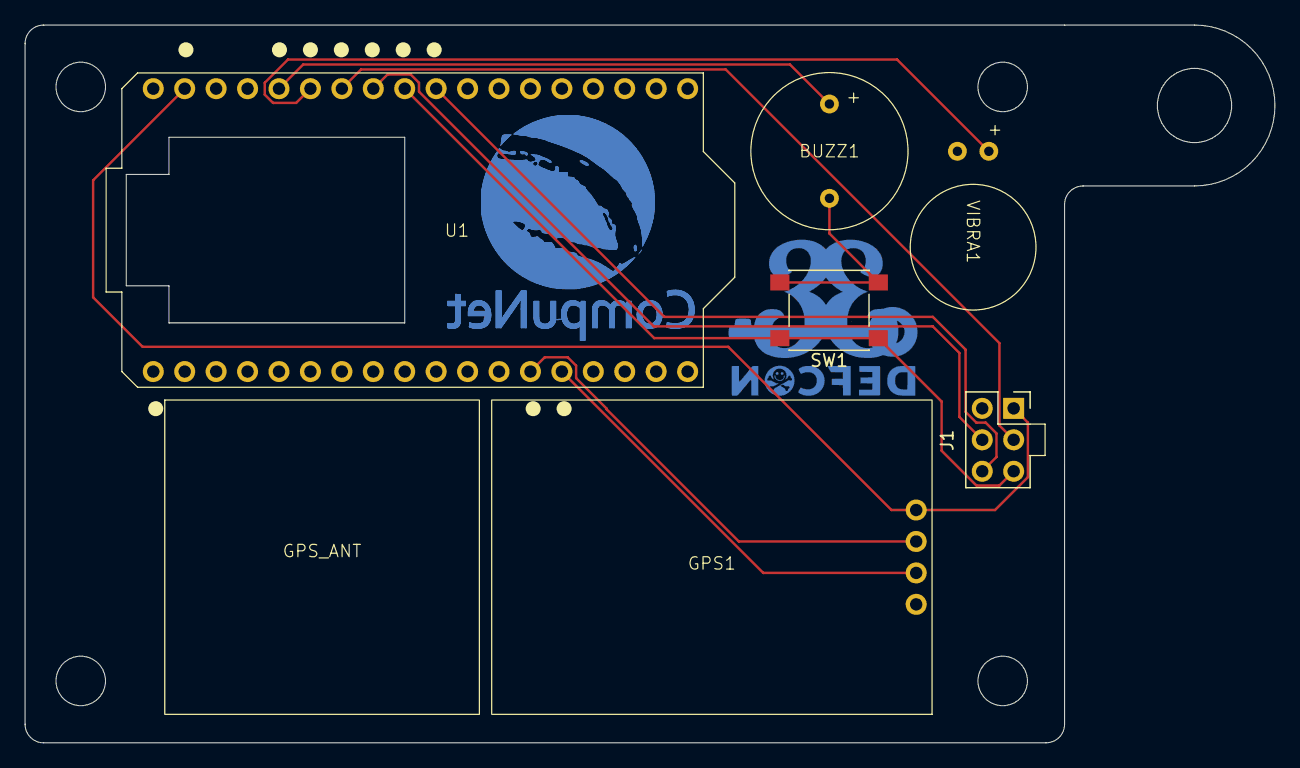
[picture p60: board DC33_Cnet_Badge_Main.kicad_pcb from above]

Board: 2 copper layers, 101.0 x 58.0 mm, 8 parts (1 on the bottom side), 10 nets.

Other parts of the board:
GPS_ANT: DC33_Cnet_Badge_HiLetgo_GPS_Ant
LiPo: DC33_Cnet_Badge_LiPo

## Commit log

2024-09-09 Remove Private
    [Pager_Shell.FCStd]
2024-12-05 Updated prototype PCB
    [Case 1.FCStd, Case 2.FCStd, Case_Test.FCStd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]
2024-12-05 Removed old files
    [Case 1.FCStd, Case 2.FCStd, Case_Test.FCStd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]
2024-12-09 Added 3D models
    [Buzz1.FCStd, Buzz1.step, Case_Test (1).FCStd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]
2024-12-09 FreeCAD model
    [DC33_Cnet_Badge_Main.FCStd, DC33_Cnet_Badge_Main.step]
2024-12-10 KiCad 3D Models
    [Buzz1.FCStd, Buzz1.step, Case_Test (1).FCStd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]
2024-12-13 Case_1 Files
    [Case_1-Bottom Case.stl, Case_1-Top Case.stl, Case_1.FCStd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]
2024-12-14 Case updates
    [Case_1-Bottom Case.stl, Case_1-Top Case.stl, Case_1.FCStd]
2024-12-14 Case clip
    [Case_1-Bottom Case.stl, Case_1-Clip.stl, Case_1.FCStd]
2024-12-14 Case clip update
    [Case_1-Clip.stl, Case_1.FCStd]
2024-12-15 Clip update
    [Case_1-Clip.stl, Case_1.FCStd]
2024-12-17 Case updates - PETG
2024-12-17 Case clip updates
    [Case_1-Clip.stl, Case_1.FCStd]
2025-01-10 Incremental Updates
    [meshtastic_cli_config.txt]
2025-03-21 Updated case
    [Case_2.FCStd, DC33_Cnet_Badge_Main.kicad_pcb, DC33_Cnet_Badge_Main.kicad_sch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]
2025-03-24 Updated PCB
    [Case_2.FCStd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]
2025-05-05 SAO Updates
    [DC31_Cnet_Badge_SAO-B_Cu.gbr, DC31_Cnet_Badge_SAO-B_Mask.gbr, DC31_Cnet_Badge_SAO-B_Paste.gbr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]
2025-05-23 Latest updates
    [Case_2-Bottom Case.stl, Case_2-Top Case.stl, Case_2.FCStd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]
2025-05-23 Clean up
    [DC33_Cnet_Badge_Main-B_Cu.gbr, DC33_Cnet_Badge_Main-B_Mask.gbr, DC33_Cnet_Badge_Main-B_Paste.gbr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]
2025-06-09 Added docs assets
    [Case_5-Bottom Case.stl, Case_5-Clip.stl, Case_5-Top Case - CNet Logo.stl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]
2025-06-10 Update Docs
    [Inventory.xlsx]
2025-07-28 Added schematics
